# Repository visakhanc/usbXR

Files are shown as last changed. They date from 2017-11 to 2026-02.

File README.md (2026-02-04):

usbXR - Low cost USB Wireless transceiver
=========================================

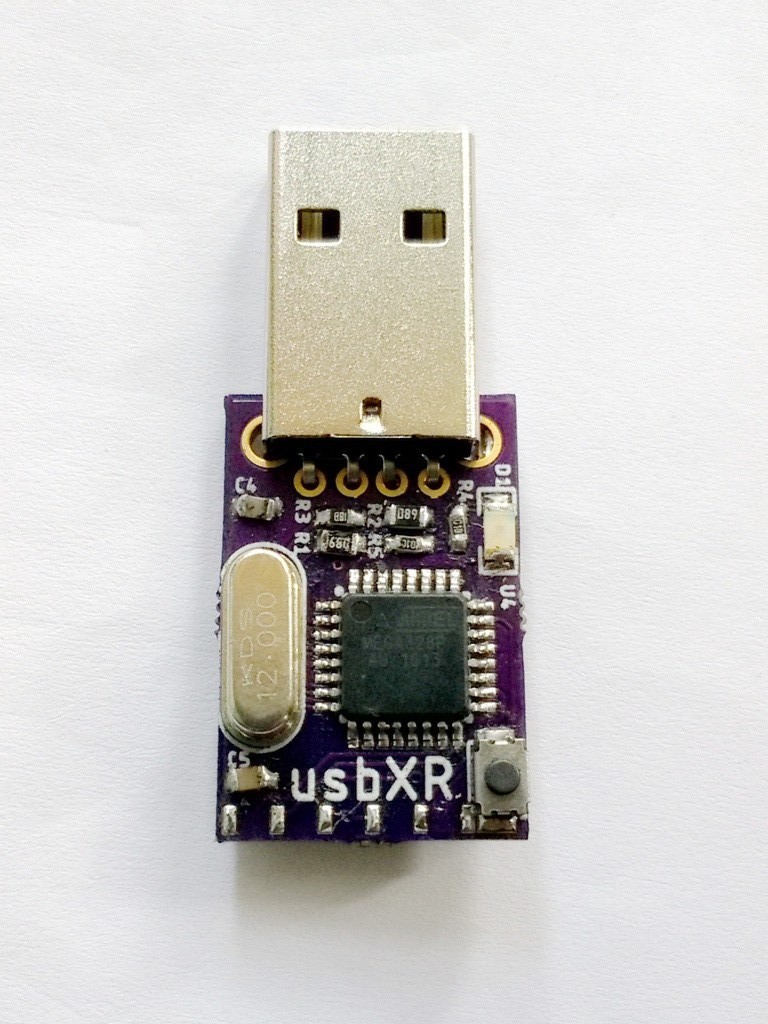
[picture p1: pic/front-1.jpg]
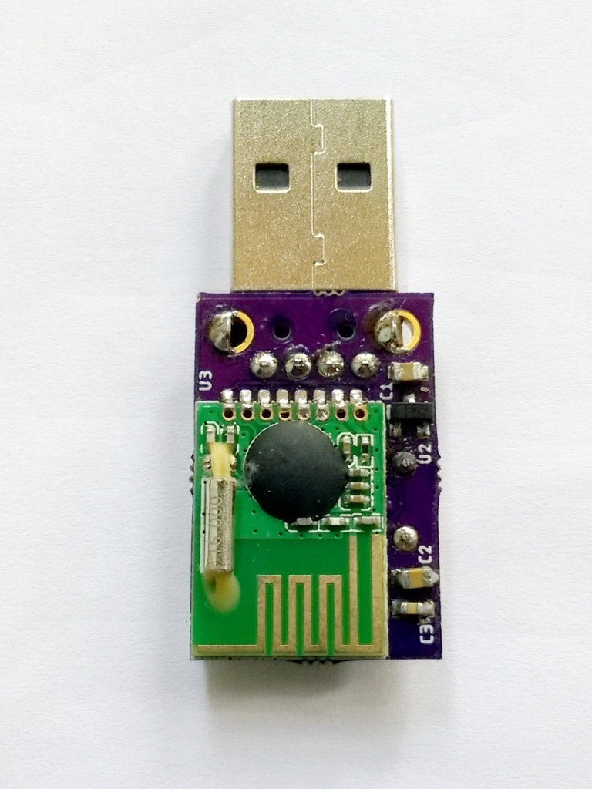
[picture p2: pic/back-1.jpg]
 

usbXR is basically a USB adapter for the RFM75 2.4GHz wireless module. The USB functionality is implemented using AVR ATmega328 and the [v-usb](https://www.obdev.at/products/vusb/index.html) firmware-only USB driver for AVRs, which emulates USB low-speed protocol. The device can be used for bi-directional communication with *remote* nodes, containing the same wireless module (ie. RFM75 or other compatible modules like RFM70/RFM73).

Once the [HID-Bootloader](https://github.com/visakhanc/usbXR/tree/master/bootloader/HID-bootloader-mega328) is flashed, you can load your application to usbXR using a command-line utility. In addition you can program remote node AVRs over-the-air! Both remote and self programming uses a single command line application bootloadHID:

`bootloadHID.exe receiver.hex` - programs usbXR device with _receiver.hex_

`bootloadHID.exe remote transmitter.hex` - programs a remote node with _transmitter.hex_

`bootloadHID.exe -r test.hex` - programs usbXR with _test.hex_ and resets usbXR
	
For over-the-air programming, the remote AVR need to be initially programmed with a bootloader. An example for ATmega8 is given [here](https://github.com/visakhanc/usbXR/tree/master/bootloader/remote-bootloader-mega8).
	
[applications](https://github.com/visakhanc/usbXR/tree/master/applications) directory contains example applications.

Hardware
--------

The hardware is simple and can only cost as low as 5 USD to make. [hardware](https://github.com/visakhanc/usbXR/tree/master/hardware) directory contains the eagle schematic and layout with Partlist.
You can order the PCBs from [OSHpark](https://oshpark.com/shared_projects/8Y8Vg5b4).

Setup
-----

HID bootloader need to be programmed to the AVR to make use of self and remote programming over USB. The bootloader and the command-line utility is an extension to the official HID [bootloader](https://www.obdev.at/products/vusb/bootloadhid.html) from v-usb, modified to incorporate remote bootloading functionality. 

**IMPORTANT:** Before building any AVR projects from this repository, [common-libs](https://github.com/visakhanc/common_libs) repository needs to be downloaded first. This contains many device libraries for AVRs such as RFM70 etc. Download it and rename the directory to 'common'. Downloaded repositories must be at same directory level for Makefile to work. That is:

	AVR_Projects/
	|
	|-- common/
	|
	|-- usbXR/

#### Bootloader

For building the bootloader firmware under Windows, WinAVR is needed. To flash the AVR, after the hardware is ready, connect an ISP programmer like USBasp to the 6 ISP pins of usbXR. Make sure to provide only 3.3v target voltage from the programmer. 5v would damage the RFM70 transceiver. To compile and program the HID-Bootloader, go into the bootloader directory and execute these steps:

1. make clean
2. make all
3. make fuse
4. make program

*If any ISP programmer other than USBasp is used, change the Makefile accordingly.*

Now, plug usbXR into a USB port while pressing down the button, and it will be recognized as an HID device (HIDBoot).

#### Bootloader utility

You will need MinGW installation to compile under Windows. To compile BootloadHID application under Windows, execute:

	make -f Makefile.windows
	
To use the bootloader, plug-in the device to a USB port while pressing down the button. The LED will be on and it is now in bootloader mode. Now use the BootloadHID application as explained earlier, to self or remote programming.

#### Remote bootloader

If you want to use the over-the-air programming feature of usbXR, a bootloader need to be initially programmed to the AVR. The example given is for ATmega8, but can be used for other AVRs with at least 2kB of boot space. The bootloader uses the last byte of the AVR EEPROM to store a validity flag. View the readme for building instructions. A button and LED is expected for a remote device. To enter bootloader, the button needs to be pressed while powering-on or resetting the AVR. Now, the bootloadHID tool can be used for programming. The LED flashes at 1 sec interval, when over-the-air programming is in progress until the programming is over. If programming fails midway, the command needs to be repeated. Programming is successful only when the LED stops flashing.

Applications
------------

An [example](https://github.com/visakhanc/usbXR/tree/master/applications/SensorReceive) shows a remote node sending 3 axis accelerometer values from MPU6050 sensor, continuously to usbXR and plotting the values in real-time. Here, interrupt-in endpoint is used to transfer the received samples over USB, at intervals as short as 10ms. Since it uses HID protocol, no driver is required under Windows. A WPF C# application is used to get USB packets and draw the graph. 

A video showing this example is [here](https://www.youtube.com/watch?v=QmQyY-55VSc).

Please visit [v-usb](https://www.obdev.at/products/vusb/index.html) for more details of implementating USB devices using v-usb library. For easy access of USB device, PyUSB python library can be used.

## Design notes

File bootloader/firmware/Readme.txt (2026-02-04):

This is official HID bootloader from v-usb modified for the usbXR board with ATmega328/ATmega8

Steps for flashing a fresh board:
=================================

1. Connect an ISP programmer to the 6 ISP pins of usbXR board. 
Make sure to provide only 3.3v target voltage from the programmer. 
5v would damage the NRF24 transceiver. If any ISP programmer
other than USBasp is used, change the Makefile accordingly.

2. From the command line, execute these commands:

    1) make clean
    2) make all
    3) make fuse
    4) make program

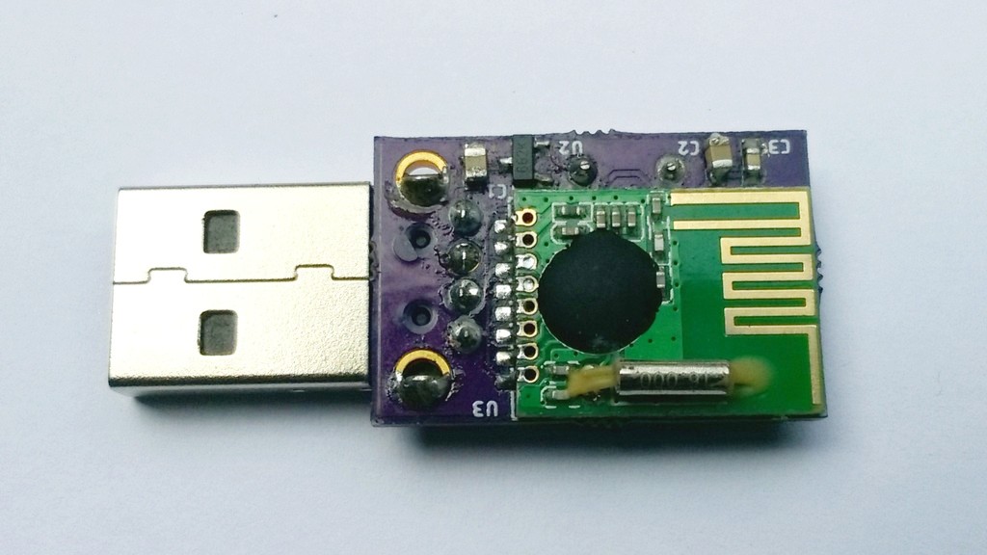
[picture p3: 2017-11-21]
pic/back.jpg

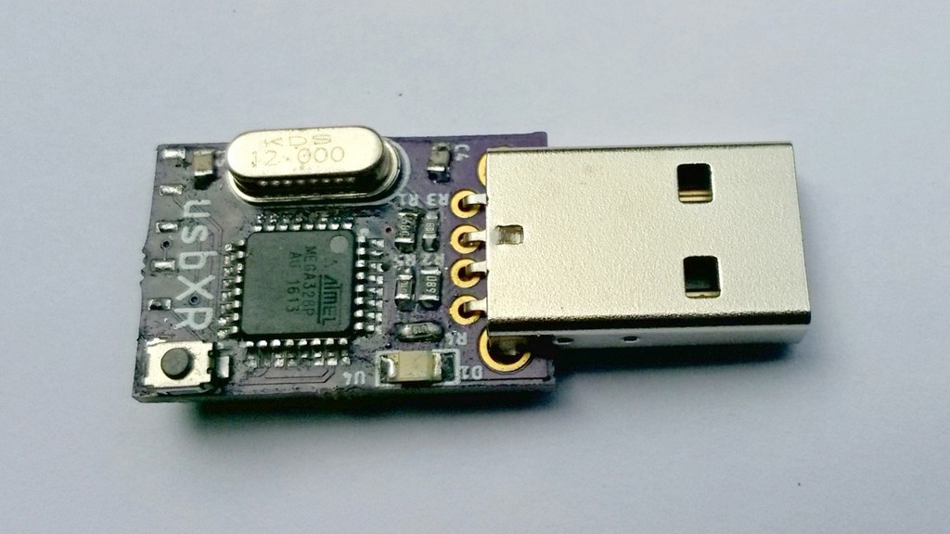
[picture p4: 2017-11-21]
pic/front.jpg

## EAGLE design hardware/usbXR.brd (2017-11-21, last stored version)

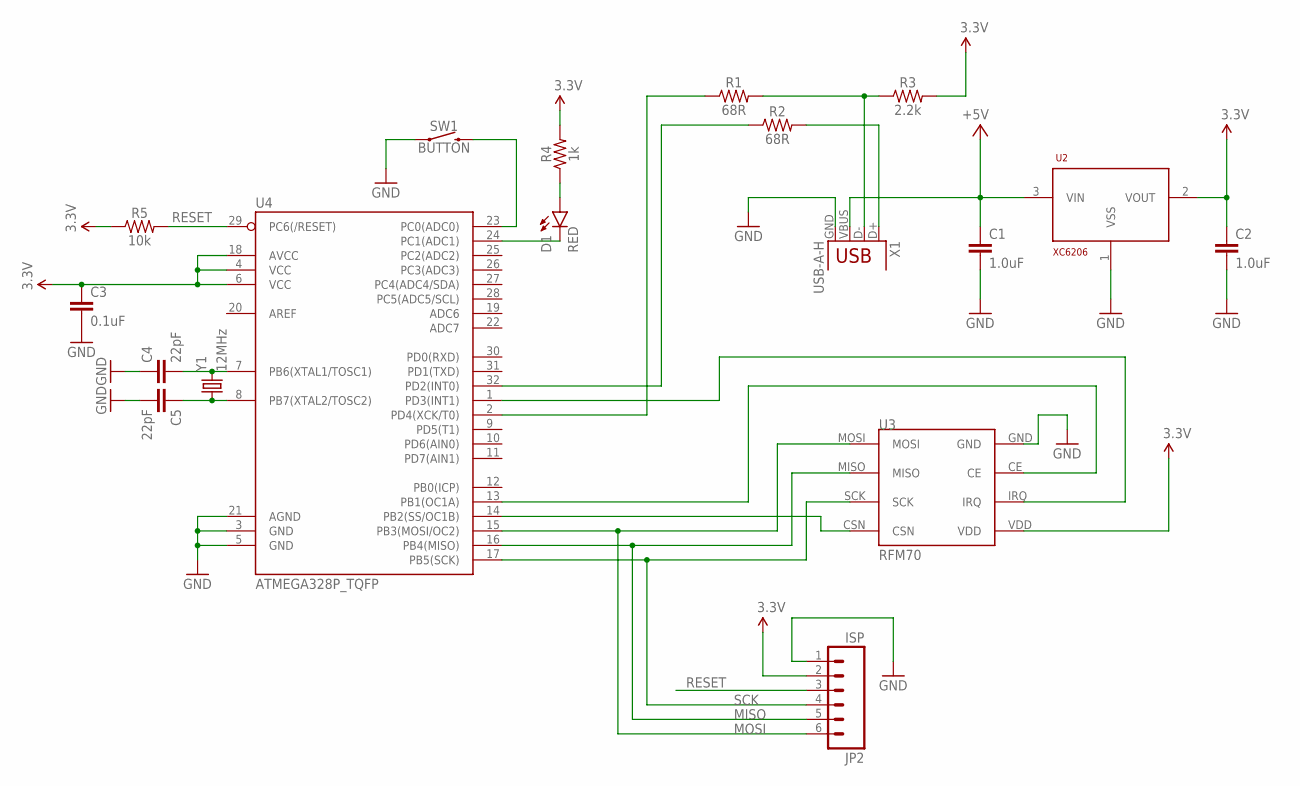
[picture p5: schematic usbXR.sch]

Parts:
C1, C2: 1.0uF; 0603
C3: 0.1uF; 0603
C4, C5: 22pF; 0603
D1: RED; LED-1206
JP2: ISP; 1X06-SMD_EDGE
R1, R2: 68R; 0603
R3: 2.2k; 0603
R4: 1k; 0603
R5: 10k; 0603
SW1: BUTTON; TACTILE_SWITCH_3X4MM
U2: XC6206; SOT23-3
U3: RFM70; RFM70_SMD
U4: ATMEGA328P_TQFP; TQFP32-08
X1: USB-A-H
Y1: 12MHz; HC49US

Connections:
3.3V: C2.1, C3.1, JP2.2, R3.2, R4.2, R5.1, U2.2 (VOUT), U3.VDD, U4.4 (VCC), U4.6 (VCC), U4.18 (AVCC)
+5V: C1.1, U2.3 (VIN), X1.VBUS
CE: U3.CE, U4.13 (PB1(OC1A))
CSN: U3.CSN, U4.14 (PB2(SS/OC1B))
GND: C1.2, C2.2, C3.2, C4.1, C5.2, JP2.1, SW1.1, U2.1 (VSS), U3.GND, U4.3 (GND), U4.5 (GND), U4.21 (AGND), X1.GND
IRQ: U3.IRQ, U4.1 (PD3(INT1))
LED: D1.C, U4.24 (PC1(ADC1))
MISO: JP2.5, U3.MISO, U4.16 (PB4(MISO))
MOSI: JP2.6, U3.MOSI, U4.15 (PB3(MOSI/OC2))
unnamed: R1.2, R3.1, X1.D-
unnamed: R2.2, X1.D+
unnamed: D1.A, R4.1
unnamed: C4.2, U4.7 (PB6(XTAL1/TOSC1)), Y1.2
unnamed: C5.1, U4.8 (PB7(XTAL2/TOSC2)), Y1.1
RESET: JP2.3, R5.2, U4.29 (PC6(/RESET))
SCK: JP2.4, U3.SCK, U4.17 (PB5(SCK))
SW: SW1.2, U4.23 (PC0(ADC0))
USB_DM: R1.1, U4.2 (PD4(XCK/T0))
USB_DP: R2.1, U4.32 (PD2(INT0))

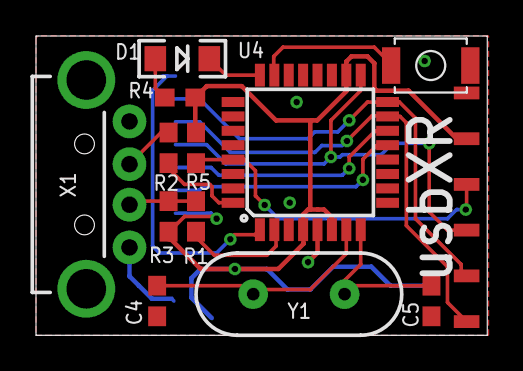
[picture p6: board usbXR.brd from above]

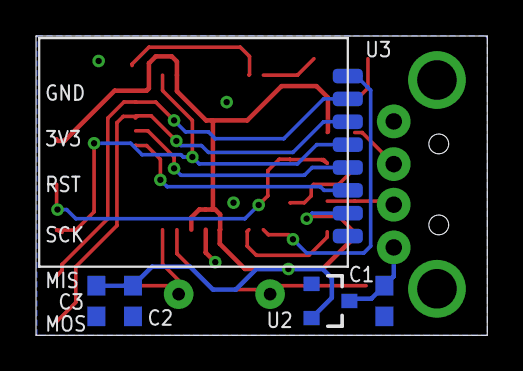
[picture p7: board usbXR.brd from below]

Board: 2 copper layers, 25.1 x 16.6 mm, 18 parts (5 on the bottom side), 19 nets.

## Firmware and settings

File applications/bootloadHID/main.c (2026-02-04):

/* Name: main.c
 * Project: AVR bootloader HID
 * Author: Christian Starkjohann
 * Creation Date: 2007-03-19
 * Tabsize: 4
 * Copyright: (c) 2007 by OBJECTIVE DEVELOPMENT Software GmbH
 * License: Proprietary, free under certain conditions. See Documentation.
 * This Revision: $Id$
 *
 * Modified: 19-Nov-2017
 * By: Visakhan C
 * For: usbXR project: https://github.com/visakhanc/usbXR
 */



#include <stdio.h>
#include <string.h>
#include <stdlib.h>
#include <errno.h>
#include <stdint.h>
#include <windows.h>
#include "usbcalls.h"
#include <stdbool.h>

#ifdef WIN32
#include <windows.h>
#elif _POSIX_C_SOURCE >= 199309L
#include <time.h>   // for nanosleep
#else
#include <unistd.h> // for usleep
#endif

#include "../../firmware/bootloader/bootloader_defs.h"


#define IDENT_VENDOR_NUM        	0x16c0
#define IDENT_VENDOR_STRING     	"obdev.at"
#define IDENT_PRODUCT_NUM       	1503
#define IDENT_PRODUCT_STRING    	"HIDBoot"
#define IDENT_PRODUCT_STRING_REM    "usbXR Sensor"
#define IDENT_PRODUCT_STRING_REM2   "HIDBoot Remote"


/* ------------------------------------------------------------------------- */

static char dataBuffer[65536 + 256];    /* buffer for file data */
static int  startAddress, endAddress;
static char leaveBootLoader = 0;

/* ------------------------------------------------------------------------- */

static void sleep_ms(int milliseconds) // cross-platform sleep function
{
#ifdef WIN32
    Sleep(milliseconds);
#elif _POSIX_C_SOURCE >= 199309L
    struct timespec ts;
    ts.tv_sec = milliseconds / 1000;
    ts.tv_nsec = (milliseconds % 1000) * 1000000;
    nanosleep(&ts, NULL);
#else
    usleep(milliseconds * 1000);
#endif
}


static int  parseUntilColon(FILE *fp)
{
int c;

    do{
        c = getc(fp);
    }while(c != ':' && c != EOF);
    return c;
}

static int  parseHex(FILE *fp, int numDigits)
{
int     i;
char    temp[9];

    for(i = 0; i < numDigits; i++)
        temp[i] = getc(fp);
    temp[i] = 0;
    return strtol(temp, NULL, 16);
}

/* ------------------------------------------------------------------------- */

static int  parseIntelHex(char *hexfile, char buffer[65536 + 256], int *startAddr, int *endAddr)
{
int     address, base, d, segment, i, lineLen, sum;
FILE    *input;

    input = fopen(hexfile, "r");
    if(input == NULL){
        fprintf(stderr, "error opening %s: %s\n", hexfile, strerror(errno));
        return 1;
    }
    while(parseUntilColon(input) == ':'){
        sum = 0;
        sum += lineLen = parseHex(input, 2);
        base = address = parseHex(input, 4);
        sum += address >> 8;
        sum += address;
        sum += segment = parseHex(input, 2);  /* segment value? */
        if(segment != 0)    /* ignore lines where this byte is not 0 */
            continue;
        for(i = 0; i < lineLen ; i++){
            d = parseHex(input, 2);
            buffer[address++] = d;
            sum += d;
        }
        sum += parseHex(input, 2);
        if((sum & 0xff) != 0){
            fprintf(stderr, "Warning: Checksum error between address 0x%x and 0x%x\n", base, address);
        }
        if(*startAddr > base)
            *startAddr = base;
        if(*endAddr < address)
            *endAddr = address;
    }
    fclose(input);
    return 0;
}

/* ------------------------------------------------------------------------- */

char    *usbErrorMessage(int errCode)
{
static char buffer[80];

    switch(errCode){
        case USB_ERROR_ACCESS:      return "Access to device denied";
        case USB_ERROR_NOTFOUND:    return "The specified device was not found";
        case USB_ERROR_BUSY:        return "The device is used by another application";
        case USB_ERROR_IO:          return "Communication error with device";
        default:
            sprintf(buffer, "Unknown USB error %d", errCode);
            return buffer;
    }
    return NULL;    /* not reached */
}

static int  getUsbInt(char *buffer, int numBytes)
{
int shift = 0, value = 0, i;

    for(i = 0; i < numBytes; i++){
        value |= ((int)*buffer & 0xff) << shift;
        shift += 8;
        buffer++;
    }
    return value;
}

static void setUsbInt(char *buffer, int value, int numBytes)
{
int i;

    for(i = 0; i < numBytes; i++){
        *buffer++ = value;
        value >>= 8;
    }
}

/* ------------------------------------------------------------------------- */

typedef struct deviceInfo {
    char    reportId;
    char    pageSize[2];
    char    flashSize[4];
} deviceInfo_t;

typedef struct deviceData {
    char    reportId;
    char    address[3];
    char    data[128];
} deviceData_t;

static int uploadData(char *dataBuffer, int startAddr, int endAddr)
{
	usbDevice_t *dev = NULL;
	int err = 0, len, mask, pageSize, deviceSize;
	union {
		char            bytes[1];
		deviceInfo_t    info;
		deviceData_t    data;
	} buffer;

    if((err = usbOpenDevice(&dev, IDENT_VENDOR_NUM, IDENT_VENDOR_STRING, IDENT_PRODUCT_NUM, IDENT_PRODUCT_STRING, 1)) != 0){
        fprintf(stderr, "Error opening HIDBoot device: %s\n", usbErrorMessage(err));
        goto errorOccurred;
    }
    len = sizeof(buffer);
    if(endAddr > startAddr) {    // We need to upload data
        if((err = usbGetReport(dev, USB_HID_REPORT_TYPE_FEATURE, 1, buffer.bytes, &len)) != 0){
            fprintf(stderr, "Error reading page size: %s\n", usbErrorMessage(err));
            goto errorOccurred;
        }
        if(len < sizeof(buffer.info)) {
            fprintf(stderr, "Not enough bytes in device info report (%d instead of %d)\n", len, (int)sizeof(buffer.info));
            err = -1;
            goto errorOccurred;
        }
        pageSize = getUsbInt(buffer.info.pageSize, 2);
        deviceSize = getUsbInt(buffer.info.flashSize, 4);
        printf("Page size   = %d (0x%x)\n", pageSize, pageSize);
        printf("Device size = %d (0x%x); %d bytes remaining\n", deviceSize, deviceSize, deviceSize - 2048);
        if(endAddr > deviceSize - 2048) {
            fprintf(stderr, "Data (%d bytes) exceeds remaining flash size!\n", endAddr);
            err = -1;
            goto errorOccurred;
        }
        if(pageSize < 128) {
            mask = 127;
        } else {
            mask = pageSize - 1;
        }
        startAddr &= ~mask;                  /* round down */
        endAddr = (endAddr + mask) & ~mask;  /* round up */
        printf("Uploading %d (0x%x) bytes starting at %d (0x%x)\n", endAddr - startAddr, endAddr - startAddr, startAddr, startAddr);
        while(startAddr < endAddr) {
            buffer.data.reportId = 2;
            memcpy(buffer.data.data, dataBuffer + startAddr, 128);
            setUsbInt(buffer.data.address, startAddr, 3);
            printf("\r0x%05x ... 0x%05x", startAddr, startAddr + (int)sizeof(buffer.data.data));
            fflush(stdout);
            if((err = usbSetReport(dev, USB_HID_REPORT_TYPE_FEATURE, buffer.bytes, sizeof(buffer.data))) != 0) {
                fprintf(stderr, "Error uploading data block: %s\n", usbErrorMessage(err));
                goto errorOccurred;
            }
            startAddr += sizeof(buffer.data.data);
        }
        printf("\n");
    }
    if(leaveBootLoader) {
        /* and now leave boot loader: */
        buffer.info.reportId = 1;
        usbSetReport(dev, USB_HID_REPORT_TYPE_FEATURE, buffer.bytes, sizeof(buffer.info));
        /* Ignore errors here. If the device reboots before we poll the response,
         * this request fails.
         */
    }
errorOccurred:
    if(dev != NULL)
        usbCloseDevice(dev);
    return err;
}




typedef struct remoteDeviceInfo {
    uint8_t		reportId;
    uint8_t 	deviceId;
    uint8_t 	statusType;
    uint8_t     devStatus;
    uint8_t   	pageSizeDiv2;
    uint8_t   	flashSizeInKB;
	uint8_t 	_padding[2];
} remoteDeviceInfo_t;

typedef struct progStatus {
	uint8_t		reportId;
	uint8_t 	txStatus;
    uint8_t 	deviceId;
    uint8_t 	statusType;
	uint8_t     devStatus;
	uint8_t 	_padding[3];
} progStatus_t;

typedef struct progCommand {
	uint8_t     reportId;
    uint8_t     deviceId;
	uint8_t     cmd;
	uint8_t     _padding[5];
} progCommand_t;

typedef struct remoteDeviceData {
    char    reportId;
    char    address[3];
    char    data[16];
} remoteDeviceData_t;


static int uploadDataRemote(char *dataBuffer, int startAddr, int endAddr)
{
	usbDevice_t *dev = NULL;
	int err = 0, len, mask, pageSize, deviceSize, retry;
	int currentAddr;
    uint8_t deviceId;
    union {
		char            	bytes[1];
		remoteDeviceData_t  progData;
		progCommand_t 		progCommand;
	} txBuffer;
	union {
		char 				bytes[1];
		remoteDeviceInfo_t	devInfo;
		progStatus_t 		progStatus;
	} replyBuffer;


    if((err = usbOpenDevice(&dev, IDENT_VENDOR_NUM, IDENT_VENDOR_STRING, IDENT_PRODUCT_NUM, IDENT_PRODUCT_STRING_REM, 1)) != 0) {
    	if((err = usbOpenDevice(&dev, IDENT_VENDOR_NUM, IDENT_VENDOR_STRING, IDENT_PRODUCT_NUM, IDENT_PRODUCT_STRING_REM2, 1)) != 0) {
			fprintf(stderr, "Error opening '%s' or '%s' device: %s\n", IDENT_PRODUCT_STRING_REM, IDENT_PRODUCT_STRING_REM2, usbErrorMessage(err));
			goto errorOccurred;
    	}
    	else {
    		printf("OPENED '%s' (VID:0x%04x PID:0x%04x) device\n", IDENT_PRODUCT_STRING_REM2, IDENT_VENDOR_NUM, IDENT_PRODUCT_NUM);
    	}
    }
    else {
    	printf("OPENED '%s' (VID:0x%04x PID:0x%04x) device\n", IDENT_PRODUCT_STRING_REM, IDENT_VENDOR_NUM, IDENT_PRODUCT_NUM);
    }

    if(endAddr > startAddr) {  // We need to upload data
		printf("GETTING Remote device info...");
        len = sizeof(replyBuffer);
        /* Get device info reported by the remote device */
        if((err = usbGetReport(dev, USB_HID_REPORT_TYPE_FEATURE, 3, replyBuffer.bytes, &len)) != 0) {
            fprintf(stderr, "USBError reading remote device info: %s\n", usbErrorMessage(err));
            goto errorOccurred;
        }
        if(len < sizeof(replyBuffer.devInfo)) {
            fprintf(stderr, "Not enough bytes in device info report (%d instead of %d)\n", len, (int)sizeof(replyBuffer.devInfo));
            err = -1;
            goto errorOccurred;
        }
        if ((replyBuffer.devInfo.devStatus != STATUS_OTA_BOOT_REQ) || (replyBuffer.devInfo.statusType != STATUS_TYPE_DEVINFO) || (!replyBuffer.devInfo.deviceId))  {	/* Invalid device info from remote device */
            printf("Device info not yet received from a remote device\n");
            err = -1;
            goto errorOccurred;
        }
        printf("OK\n");

		/* Command the remote device to start receiving data */
        deviceId = replyBuffer.devInfo.deviceId;
        txBuffer.progCommand.reportId = 3;
        txBuffer.progCommand.deviceId = deviceId;
        txBuffer.progCommand.cmd = CMD_OTA_BOOT_START;
        if((err = usbSetReport(dev, USB_HID_REPORT_TYPE_FEATURE, txBuffer.bytes, sizeof(txBuffer.progCommand))) != 0) {
            fprintf(stderr, "USBError sending PROG_START command: %s\n", usbErrorMessage(err));
            err = -1;
            goto errorOccurred;
        }

        /* Wait for acknowledgment from remote device */
        printf("WAITING for Remote device (ID: 0x%02x) to get ready", deviceId);
        retry = 50;
        while(retry) {
            putchar('.');
             if((err = usbGetReport(dev, USB_HID_REPORT_TYPE_FEATURE, 3, replyBuffer.bytes, &len)) != 0) {
                fprintf(stderr, "USBError reading remote device info: %s\n", usbErrorMessage(err));
                goto errorOccurred;
            }
             if(len < sizeof(replyBuffer.devInfo)) {
                fprintf(stderr, "Not enough bytes in device info report (%d instead of %d)\n", len, (int)sizeof(replyBuffer.devInfo));
                err = -1;
                goto errorOccurred;
            }
            if((replyBuffer.devInfo.deviceId == deviceId) && (replyBuffer.devInfo.devStatus == STATUS_OTA_BOOT_READY)) {
                break;
            }
            retry--;
            Sleep(200);
        }
        if(!retry) {
            printf("Timeout\n");
            printf("No response from Remote device! deviceID: 0x%02x Status: 0x%02x\n", replyBuffer.devInfo.deviceId, replyBuffer.devInfo.devStatus);
            goto errorOccurred;
        }
        printf("OK\n");
        //Sleep(1000); /* Delay for remote device to change to Rx mode */
        /* Acknowledgment received from remote, Change to Tx mode*/
        printf("CHANGING to Tx mode...");
        txBuffer.progCommand.reportId = 3;
        txBuffer.progCommand.cmd = CMD_OTA_BOOT_TXMODE;
        if((err = usbSetReport(dev, USB_HID_REPORT_TYPE_FEATURE, txBuffer.bytes, sizeof(txBuffer.progCommand))) != 0) {
			fprintf(stderr, "USBError sending PROG_START command: %s\n", usbErrorMessage(err));
			err = -1;
			goto errorOccurred;
		}
        printf("OK\n");

        /* Parse page size and flash size of the remote from the received device info */
        pageSize = replyBuffer.devInfo.pageSizeDiv2 * 2;
        deviceSize = replyBuffer.devInfo.flashSizeInKB * 1024;
        printf("\nPage size   = %d (0x%x)\t", pageSize, pageSize);
        printf("Device size = %d (0x%x); %d bytes remaining\n", deviceSize, deviceSize, deviceSize - 2048);
        if(endAddr > deviceSize - 2048) {
            fprintf(stderr, "Data (%d bytes) exceeds remaining flash size!\n", endAddr);
            err = -1;
            goto errorOccurred;
        }
        if(pageSize < 128) {
			mask = 127;
		} else {
			mask = pageSize - 1;
		}
		startAddr &= ~mask;                  /* round down */
		endAddr = (endAddr + mask) & ~mask;  /* round up */


		/* Transmit the data blocks now */
        printf("UPLOADING %d (0x%x) bytes starting at %d (0x%x)\n", endAddr - startAddr, endAddr - startAddr, startAddr, startAddr);
        while(startAddr < endAddr) {
            txBuffer.progData.reportId = 4;
            memcpy(txBuffer.progData.data, dataBuffer + startAddr, sizeof(txBuffer.progData.data));
            setUsbInt(txBuffer.progData.address, startAddr, 3);
            printf("\n0x%05x ... 0x%05x: ", startAddr, startAddr + (int)sizeof(txBuffer.progData.data));
            fflush(stdout);
			retry = 5;
			while(retry) {
				Sleep(10);
				putchar('.');
				/* Send data block to remote device */
				if((err = usbSetReport(dev, USB_HID_REPORT_TYPE_FEATURE, txBuffer.bytes, sizeof(txBuffer.progData))) != 0) {
					//fprintf(stderr, "USBError uploading data block: %s\n", usbErrorMessage(err));
					//goto errorOccurred;
					putchar('*');
				}
				Sleep(20);
				len = sizeof(replyBuffer); /* Get the reply from remote device */
				if((err = usbGetReport(dev, USB_HID_REPORT_TYPE_FEATURE, 3, replyBuffer.bytes, &len)) != 0) {
					fprintf(stderr, "USBError getting status: %s\n", usbErrorMessage(err));
					goto errorOccurred;
				}
				if(len < sizeof(replyBuffer.progStatus)) {
					fprintf(stderr, "Not enough bytes in device info report (%d instead of %d)\n", len, (int)sizeof(replyBuffer.progStatus));
					err = -1;
					goto errorOccurred;
				}
				if ((replyBuffer.progStatus.txStatus == 0) && (replyBuffer.progStatus.deviceId == deviceId)) {
					printf("OK");
					break;
				}
				retry--;
			}
			if(!retry) {
				fprintf(stderr, "ERROR: programming failed at address 0x%05x\n", startAddr);
				printf("txStatus: %d, DevID: 0x%02x, DevStatus: 0x%02x", replyBuffer.progStatus.txStatus, replyBuffer.progStatus.deviceId, replyBuffer.progStatus.devStatus);
				goto errorOccurred;
			}
            startAddr += sizeof(txBuffer.progData.data);
        }

        /* Send STOP to remote device */
		printf("\n\nENDING communication ");
		sleep_ms(10);
		txBuffer.progCommand.reportId = 3;
		txBuffer.progCommand.deviceId = deviceId;
		txBuffer.progCommand.cmd = CMD_OTA_BOOT_STOP;
		retry = 5;
		while(retry) {
			Sleep(10);
			putchar('.');
			if((err = usbSetReport(dev, USB_HID_REPORT_TYPE_FEATURE, txBuffer.bytes, sizeof(txBuffer.progCommand))) != 0) {
				//fprintf(stderr, "USBError: Sending STOP command: %s\n", usbErrorMessage(err));
				//goto errorOccurred;
				putchar('*');
			}
			Sleep(20);
			len = sizeof(replyBuffer);	/* Get the reply from remote device */
			if((err = usbGetReport(dev, USB_HID_REPORT_TYPE_FEATURE, 3, replyBuffer.bytes, &len)) != 0) {
				fprintf(stderr, "USBError: Getting PROG_STOP response: %s\n", usbErrorMessage(err));
			    goto errorOccurred;
			}
			if ((replyBuffer.progStatus.txStatus == 0) && (replyBuffer.progStatus.deviceId == deviceId)) {	/* Valid reply received from remote device */
				break;
			}
			retry--;
		}
		if(!retry) {
			fprintf(stderr, "\nERROR: Ending communication failed\n");
			goto errorOccurred;
		}
		printf("OK\n");

		/* Reset the remote device */
		printf("RESETTING Remote device ");
		Sleep(200);
		txBuffer.progCommand.reportId = 3;
		txBuffer.progCommand.deviceId = deviceId;
		txBuffer.progCommand.cmd = CMD_OTA_BOOT_RESET;	/* Send REBOOT to remote device */
		retry = 5;
		while(retry) {
			Sleep(10);
			putchar('.');
			if((err = usbSetReport(dev, USB_HID_REPORT_TYPE_FEATURE, txBuffer.bytes, sizeof(txBuffer.progCommand))) != 0) {
				putchar('*');
			}
			Sleep(10);
			len = sizeof(replyBuffer);	/* Get the reply from remote device */
			if((err = usbGetReport(dev, USB_HID_REPORT_TYPE_FEATURE, 3, replyBuffer.bytes, &len)) != 0) {
				fprintf(stderr, "USBError: Getting PROG_REBOOT response: %s\n", usbErrorMessage(err));
				goto errorOccurred;
			}
			if(replyBuffer.progStatus.txStatus == 0) {	/* Valid reply received from remote device */
				break;
			}
			retry--;

		}
		printf("OK\n");
    }
	
errorOccurred:
	if(dev != NULL) {
		printf("RESTORING state...");
		Sleep(200);
		txBuffer.progCommand.reportId = 3;
		txBuffer.progCommand.cmd = CMD_OTA_BOOT_END;	/* Send END command */
		if((err = usbSetReport(dev, USB_HID_REPORT_TYPE_FEATURE, txBuffer.bytes, sizeof(txBuffer.progCommand))) != 0) {
			fprintf(stderr, "USBError: Sending END command: %s\n", usbErrorMessage(err));
			return 1;
		}
		printf("OK\n");
        usbCloseDevice(dev);
	}
    return err;
}




/* ------------------------------------------------------------------------- */

static void printUsage(char *pname)
{
    fprintf(stderr, "usage: %s [remote] [-r] [<intel-hexfile>]\n", pname);
}

int main(int argc, char **argv)
{
char    *file = NULL;
bool	remoteBoot = false;
int 	count = 1;

    if(argc < 2) {
        printUsage(argv[0]);
        return 1;
    }
    if(strcmp(argv[1], "-h") == 0 || strcmp(argv[1], "--help") == 0) {
        printUsage(argv[0]);
        return 1;
    }
	argv++;
	if(strcmp(*argv, "remote") == 0) {
		remoteBoot = true;
		argv++;
		count++;
	}
	if((count < argc) && (strcmp(*argv, "-r") == 0)) {
		leaveBootLoader = 1;
		argv++;
		count++;
	}
	if(count < argc) {
		file = *argv;
	}


    startAddress = sizeof(dataBuffer);
    endAddress = 0;
    if(file != NULL) {   // an upload file was given, load the data
        memset(dataBuffer, -1, sizeof(dataBuffer));
        if(parseIntelHex(file, dataBuffer, &startAddress, &endAddress))
            return 1;
        if(startAddress >= endAddress){
            fprintf(stderr, "No data in input file, exiting.\n");
            return 0;
        }
    }
    // if no file was given, endAddress is less than startAddress and no data is uploaded
	if(remoteBoot) {
		if(uploadDataRemote(dataBuffer, startAddress, endAddress))
			return 1;		
	}
	else {
		if(uploadData(dataBuffer, startAddress, endAddress))
			return 1;
	}
    return 0;
}

/* ------------------------------------------------------------------------- */

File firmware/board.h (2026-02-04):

/*
 *  board.h
 *
 *	Pin definitions and Macros for usbXR
 *
 *  Created on: Jan 29, 2026
 *      Author: Visakhan
 */

#ifndef BOARD_H_
#define BOARD_H_


#include <avr/io.h>


/* Button and LED */
#define LED						PD6
#define LED_DDR					DDRD
#define LED_PORT				PORTD

#define BUTTON					PD5
#define BUTTON_PORT				PORTD
#define BUTTON_PIN				PIND

/* Macros for Button and LED */
#define LED_INIT()				(LED_DDR |= (1 << LED))
#define LED_OFF()				(LED_PORT |= (1 << LED))
#define LED_ON()				(LED_PORT &= ~(1 << LED))
#define LED_TOGGLE()			(LED_PORT ^= (1 << LED))
#define BUTTON_INIT()			(BUTTON_PORT |= (1 << BUTTON))
#define BUTTON_PRESSED()		((BUTTON_PIN & (1 << BUTTON)) == 0)


#endif /* BOARD_H_ */

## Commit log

2017-11-18 Initial commit with only hardware and intro
    [usbXR.brd, usbXR.sch]
2017-11-19 schematic pdf added
2017-11-20 Bootloader added
    [schematic.sch]
2017-11-20 Added example schematic for remote
2017-11-20 SChematic added for example application
    [schematic.sch]
2017-11-20 schematic removied
    [schematic.sch]
2017-11-21 schematic in PNG
    [usbXR.brd, usbXR.sch]
2026-02-04 bootloadHID application update
    [schematic.sch, usbXR.brd, usbXR.sch]
2026-02-14 board.h hardcoded inside bootloader_config.h

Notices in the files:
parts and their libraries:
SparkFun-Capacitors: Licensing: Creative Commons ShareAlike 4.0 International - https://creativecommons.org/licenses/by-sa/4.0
